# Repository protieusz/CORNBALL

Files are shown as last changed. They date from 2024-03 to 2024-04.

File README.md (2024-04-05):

# CORNBALL
A mod of the Cornelius keyboard with a 25mm integrated trackball and 4 RGBs.  Keyboard is powered by the Waveshare RP2043 Tiny that has a usb c daughterboard PCB.  The switch plate in integrated and is 5mm thick with integrated 25mm trackball holder.  The case is heavily modified from Cool536lc https://github.com/telzo2000/cool536lc to accomodate the trackball in the center.  This pcb also has the option of EVQ roller encoder or a MX switch at the top center.  The modified case files have been removed and close sourced since this is not my original design, telzo2000. You will have to design a case around my pcb.  QMK code is borrowed from aki27 with modification of adding the Cornball matrix into the layout and the rest of the core code is original.

Initial prototype PCBs have a weird flaw. The "Q" switch footprint somehow shifted upwards making it not fit in the switch plate. So I had to bend the 2 pins and cut off the bottom steam holder area in order to fit the switch plate. Then flux solder the pins. The PCB gerber files have since be corrected but untested since I don't want to waste money on another set of 5. Please print at your own risk.

Production Pics






Q Switch Hack















Fusion360 & EasyEDA Renders

Screenshot 2024-03-16 at 7 04 35 PM
Screenshot 2024-03-16 at 2 38 04 AM
Screenshot 2024-03-16 at 2 35 12 AM
Screenshot 2024-03-16 at 2 34 58 AM
Screenshot 2024-03-16 at 2 34 07 AM
Screenshot 2024-03-16 at 2 33 52 AM
Screenshot 2024-03-15 at 12 24 08 PM
Screenshot 2024-03-15 at 12 23 57 PM

Screenshot 2024-03-18 at 1 28 50 AM
Screenshot 2024-03-18 at 1 28 08 AM

Fit Test

















# License

MIT licensed.

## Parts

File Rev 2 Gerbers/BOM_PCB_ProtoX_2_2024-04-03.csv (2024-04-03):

ID | Name | Designator | Footprint | Quantity | Manufacturer Part | Manufacturer | Supplier | Supplier Part | Price | link
1 | RP2040-TINY WITH 3D MODEL | U1 | RP2040-TINY | 1 | 24664 | Waveshare |  |  |  | https://www.waveshare.com/rp2040-tiny.htm?sku=24664
2 | 4.7uF | C17,C19,C20 | C0402 | 3 | CL05A475MP5NRNC | SAMSUNG(三星) | LCSC | C23733 | 0.005 | https://lcsc.com/eda_search?q=C23733&%26type=1&ref=editor
3 | 100nF | C18 | C0402 | 1 | CL05B104KB54PNC | SAMSUNG(三星) | LCSC | C307331 | 0.005 | https://lcsc.com/eda_search?q=C307331&%26type=1&ref=editor
4 | 10kΩ | R10,R12,R13 | R0402 | 3 | 0402WGF1002TCE | UNI-ROYAL(厚声) | LCSC | C25744 | 0.001 | https://lcsc.com/eda_search?q=C25744&%26type=1&ref=editor
5 | 39Ω | R11 | R0402 | 1 | 0402WGJ0390TCE | UNI-ROYAL(厚声) | LCSC | C25164 |  | https://lcsc.com/eda_search?q=C25164&%26type=1&ref=editor
6 | 15kΩ | R14 | R0402 | 1 | 0402WGF1502TCE | UNI-ROYAL(厚声) | LCSC | C25756 | 0.001 | https://lcsc.com/eda_search?q=C25756&%26type=1&ref=editor
7 | SN74LVC1T45QDCKRQ1 | U6 | SC-70-6_L2.0-W1.3-P0.65-LS2.1-BR | 1 | SN74LVC1T45QDCKRQ1 | TI(德州仪器) | LCSC | C139353 | 0.544 | https://lcsc.com/eda_search?q=C139353&%26type=1&ref=editor
8 | AP2127K-ADJTRG1 | U8 | SOT-23-5_L3.0-W1.7-P0.95-LS2.8-BR | 1 | AP2127K-ADJTRG1 | DIODES(美台) | LCSC | C96343 | 0.055 | https://lcsc.com/eda_search?q=C96343&%26type=1&ref=editor
9 | SK6812MINI-E_C5149201 | U13,U14,U15,U16 | LED-SMD_L3.2-W2.8-TR | 4 | SK6812MINI-E | 欧思科光电 | LCSC | C5149201 | 0.162 | https://lcsc.com/eda_search?q=C5149201&%26type=1&ref=editor
10 | PMW3360DM-T2QU | U7 | PMW3360DM-T2QU.PACK | 1 | PMW3360DM-T2QU |  |  |  |  | http://www.pixart.com/upload/PMS0058-PMW3360DM-T2QU-NNDS-R1.30-06042016_20160902201411.pdf
11 | NO | ENCA,ENCB | PIN 1-PIN | 2
12 | SM4007PL | D105,D000,D001,D002,D003,D004,D006,D007,D008,D009,D010,D106,D107,D108,D109,D110,D206,D207,D208,D209,D210,D100,D101,D102,D103,D104,D200,D201,D202,D203,D204,D302,D303,D304,D307,D308,D309 | SOD-123F_L2.8-W1.8-LS3.7-RD | 37 | SM4007PL | MDD | LCSC | C64898 | 0.006 | https://item.szlcsc.com/60254.html
13 | Switch | K105,K307,K000,K001,K002,K003,K004,K006,K007,K008,K009,K010,K106,K107,K108,K109,K110,K206,K207,K208,K209,K210,K100,K101,K102,K103,K104,K200,K201,K202,K203,K204,K302,K303,K304,K308,K309 | CHERRY_MX_100_MILLMAX | 37
14 | Roll Encoder - EVQWGD001 | U105 | EVQWGD001 ENCODER | 1 | EVQWGD001 | Panasonic | Aliexpress | EVQWGD001

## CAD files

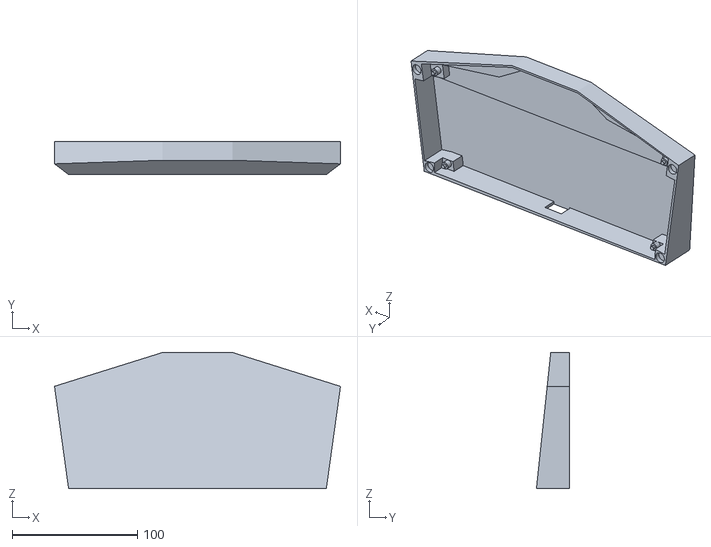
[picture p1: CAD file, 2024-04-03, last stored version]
STLs/cool536lc_bottom higher3mm.stl
228.6 x 26.5 x 108.8

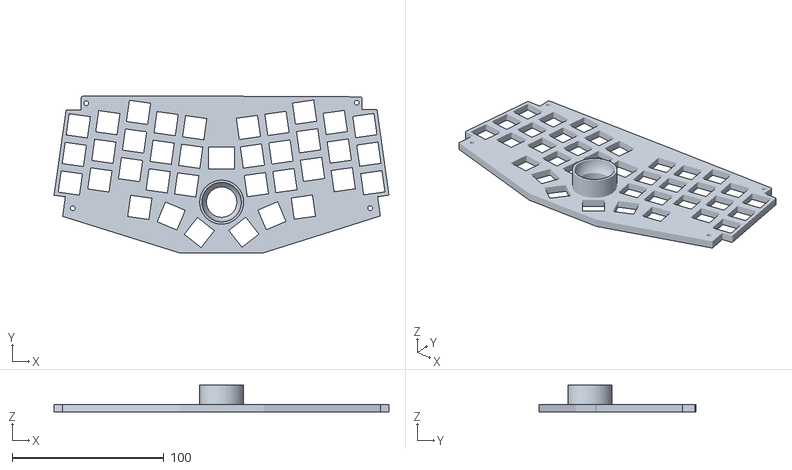
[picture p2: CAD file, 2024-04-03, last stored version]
STLs/ProtoX SwitchPlateFixedSquares.stl
221.0 x 103.3 x 17.8

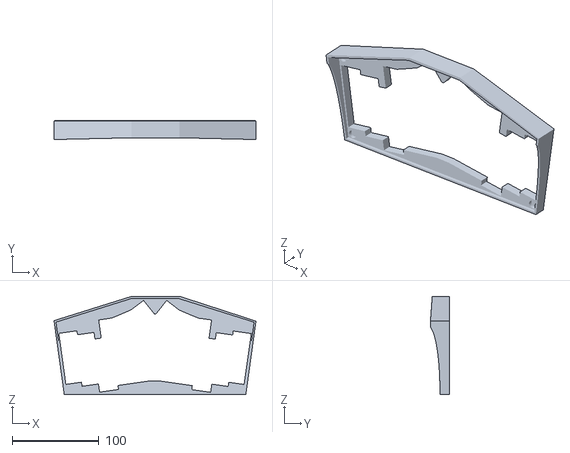
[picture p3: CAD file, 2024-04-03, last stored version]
STLs/cool536lc_top mod.stl
233.1 x 22.0 x 113.5

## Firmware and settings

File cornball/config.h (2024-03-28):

// Copyright 2023 aki27 (@aki27kbd)
// SPDX-License-Identifier: GPL-2.0-or-later

#pragma once

//#define VIAL_KEYBOARD_UID {0xC4, 0x18, 0xCC, 0x6D, 0x1C, 0x16, 0x5B, 0x8D}
//#define VIAL_UNLOCK_COMBO_ROWS {0, 0}
//#define VIAL_UNLOCK_COMBO_COLS {1, 11}

/* VIA */
//#define DYNAMIC_KEYMAP_LAYER_COUNT 8


/* key matrix size */
//#define MATRIX_COLS 13
//#define MATRIX_ROWS 4


/* tapping term */
// #define TAPPING_FORCE_HOLD
//#define TAPPING_TERM 200
// #define IGNORE_MOD_TAP_INTERRUPT

#define RP2040_BOOTLOADER_DOUBLE_TAP_RESET // Activates the double-tap behavior
#define RP2040_BOOTLOADER_DOUBLE_TAP_RESET_TIMEOUT 200U // Timeout window in ms in which the double tap can occur.

#ifdef COMBO_ENABLE
#    define COMBO_COUNT 2
#    define COMBO_TERM 200
#endif

/* Encoder */
//#define ENCODERS_PAD_A { GP11 }
//#define ENCODERS_PAD_B { GP12 }
//#define ENCODER_RESOLUTION 4

/* Matrix*/
//#define MATRIX_COL_PINS { GP25, GP24, GP23, GP22, GP21, GP26, GP27, GP20, GP19, GP18, GP17, GP16, GP13 }
//#define MATRIX_ROW_PINS { GP28, GP10, GP14, GP15 }

/* COL2ROW, ROW2COL */
//#define DIODE_DIRECTION COL2ROW


/* Set 0 if debouncing isn't needed */
//#define DEBOUNCE 5


/* Mechanical locking support. Use KC_LCAP, KC_LNUM or KC_LSCR instead in keymap (Very Important for Scroll Lock!!!) */
#undef LOCKING_SUPPORT_ENABLE
/* Locking resynchronize hack */
#undef LOCKING_RESYNC_ENABLE


/* RGB LED */
//#define WS2812_PIO_USE_PIO1
#define WS2812_DI_PIN GP0

#ifdef RGBLIGHT_ENABLE
    #define RGBLIGHT_LED_COUNT 4
    #define RGBLIGHT_LIMIT_VAL 80
    #define RGBLIGHT_HUE_STEP 10
    #define RGBLIGHT_SAT_STEP 17
    #define RGBLIGHT_VAL_STEP 17

    #define RGBLIGHT_EFFECT_BREATHING
    #define RGBLIGHT_EFFECT_RAINBOW_MOOD
    #define RGBLIGHT_EFFECT_RAINBOW_SWIRL
    #define RGBLIGHT_EFFECT_SNAKE
    #define RGBLIGHT_EFFECT_KNIGHT
    #define RGBLIGHT_EFFECT_CHRISTMAS
    #define RGBLIGHT_EFFECT_STATIC_GRADIENT
    #define RGBLIGHT_EFFECT_TWINKLE
    #define RGBLIGHT_EFFECT_ALTERNATING
#endif


/* Trackball */

#ifdef POINTING_DEVICE_ENABLE

//#    undef RP_SPI_USE_SPI0
//#    define RP_SPI_USE_SPI0 TRUE
//#    undef RP_SPI_USE_SPI1
//#    define RP_SPI_USE_SPI1 FALSE
#    define SPI_DRIVER SPID1

//#    define SPI_SCK_PIN GP22 //6
//#    define SPI_MISO_PIN GP24 //4
//#    define SPI_MOSI_PIN GP23 //7
#    define SPI_SCK_PIN GP14
#    define SPI_MISO_PIN GP12
#    define SPI_MOSI_PIN GP15

#endif


#ifndef PMW33XX_CS_PIN
#    define PMW33XX_CS_PIN GP13
#endif
//#define POINTING_DEVICE_INVERT_X
//#define POINTING_DEVICE_INVERT_Y
//#define ROTATIONAL_TRANSFORM_ANGLE 90
//#define POINTING_DEVICE_ROTATION_90

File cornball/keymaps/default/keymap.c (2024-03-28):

/*
Copyright 2022 aki27

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
You should have received a copy of the GNU General Public License
along with this program.  If not, see <http://www.gnu.org/licenses/>.
*/

#include QMK_KEYBOARD_H

enum combo_events {
  COMBO_DEL,
  COMBO_ESC,
  //COMBO_RCLICK,
  COMBO_LENGTH
};
uint16_t COMBO_LEN = COMBO_LENGTH;

const uint16_t PROGMEM combo_del[] = {KC_Y, KC_H, COMBO_END};
const uint16_t PROGMEM combo_esc[] = {KC_T, KC_G, COMBO_END};
//const uint16_t PROGMEM combo_rclick[] = {KC_MS_BTN1, SCRL_MO, COMBO_END};

combo_t key_combos[] = {
  [COMBO_DEL] = COMBO(combo_del, KC_DEL),
  [COMBO_ESC] = COMBO(combo_esc, KC_ESC),
  //[COMBO_RCLICK] = COMBO(combo_rclick, KC_MS_BTN2),
};

layer_state_t layer_state_set_user(layer_state_t state) {
    return update_tri_layer_state(state, 1, 2, 3);
} 

enum layer_names {
  _BASE,
  _FN1,
  _FN2,
  _FN3
};

const uint16_t PROGMEM keymaps[][MATRIX_ROWS][MATRIX_COLS] = {
    
    [_BASE] = LAYOUT(
        KC_Q,         KC_W, KC_E,    KC_R,    KC_T,                            KC_Y,          KC_U,          KC_I,     KC_O,   KC_P,
        KC_A,         KC_S, KC_D,    KC_F,    KC_G,             SCRL_MO,       KC_H,          KC_J,          KC_K,     KC_L,   KC_SCLN,
        LSFT_T(KC_Z), KC_X, KC_C,    KC_V,    KC_B,                            KC_N,          KC_M,          KC_COMMA, KC_DOT, RSFT_T(KC_SLSH),
                            KC_LGUI, KC_LCTL, LT(1,KC_BSPC),                   LT(2,KC_SPC),  (KC_ENT),      KC_LALT
    ),
    [_FN1] = LAYOUT(
        KC_1,    KC_2,    KC_3,    KC_4,    KC_5,                               KC_6,       KC_7,       KC_8,    KC_9,    KC_0,
        KC_TAB,  _______, _______, _______, _______,             _______,       KC_MINS,    KC_EQL,     KC_LBRC, KC_RBRC, KC_QUOT,
        _______, _______, KC_MUTE, KC_VOLD, KC_VOLU,                            KC_TILD,    KC_GRV,     _______, _______, KC_BSLS,
                          _______, _______, _______,                            KC_MS_BTN1, KC_MS_BTN2, _______
    ),
    [_FN2] = LAYOUT(
        KC_EXLM, KC_AT,   KC_HASH, KC_DLR,  KC_PERC,                            KC_CIRC, KC_AMPR, KC_ASTR, KC_LPRN, KC_RPRN,
        RGB_VAI,  RGB_SAI,  RGB_HUI,  RGB_SPI, RGB_MOD,          _______,       RGB_TOG,  _______,  _______,   _______, _______,
        RGB_VAD,  RGB_SAD,  RGB_HUD,  RGB_SPD, RGB_RMOD,                        _______,  _______, _______, _______, _______,
                          _______, _______, _______,                            _______,  _______, _______
    ),
    [_FN3] = LAYOUT(
        _______, KC_UP, _______, _______, _______,                              KC_F1,   KC_F2,   KC_F3,   KC_F4,   KC_PSCR,
        KC_LEFT, KC_DOWN, KC_RIGHT, _______, _______,            _______,       KC_F5,   KC_F6,   KC_F7,   KC_F8,   KC_F9,
        _______, _______, ROT_L15, ROT_R15, CPI_SW,                             KC_F10,  KC_F11,  KC_F12,  _______, _______,
                          _______, _______, _______,                            _______, _______, _______
    )
};

//bool encoder_update_user(uint8_t index, bool clockwise) {
    //if (index == 0) {
        //if (clockwise) {
            //tap_code(KC_VOLD);
            //tap_code(KC_MS_WH_UP);
        //} else {
            //tap_code(KC_VOLU);
            //tap_code(KC_MS_WH_DOWN);
        //}
    //}
    //return true;
//}

//#if defined(ENCODER_MAP_ENABLE)
//const uint16_t PROGMEM encoder_map[][NUM_ENCODERS][2] = {
    //[0] =  { ENCODER_CCW_CW(KC_MS_WH_UP, KC_MS_WH_DOWN)  },
    //[1] =  { ENCODER_CCW_CW(KC_MS_WH_LEFT, KC_MS_WH_RIGHT)  },
    //[2] =  { ENCODER_CCW_CW(KC_PGUP, KC_PGDN)  },
    //[3] =  { ENCODER_CCW_CW(KC_VOLD, KC_VOLU)  } 
    //[4] =  { ENCODER_CCW_CW(XXXXXXX, XXXXXXX) }
//};
//#endif

//keyevent_t encoder1_ccw = {
    //.key = (keypos_t){.row = 3, .col = 0},
    //.pressed = false
//};

//keyevent_t encoder1_cw = {
    //.key = (keypos_t){.row = 3, .col = 9},
    //.pressed = false
//};

//bool encoder_update_user(uint8_t index, bool clockwise) {
    //if (index == 0) { /* First encoder */
        //if (clockwise) {
            //encoder1_cw.pressed = true;
            //encoder1_cw.time = (timer_read() | 1);
            //action_exec(encoder1_cw);
        //} else {
            //encoder1_ccw.pressed = true;
            //encoder1_ccw.time = (timer_read() | 1);
            //action_exec(encoder1_ccw);
        //}
    //}

    //return true;
//}

//void matrix_scan_user(void) {

    //if (IS_PRESSED(encoder1_ccw)) {
        //encoder1_ccw.pressed = false;
        //encoder1_ccw.time = (timer_read() | 1);
        //action_exec(encoder1_ccw);
    //}

    //if (IS_PRESSED(encoder1_cw)) {
        //encoder1_cw.pressed = false;
        //encoder1_cw.time = (timer_read() | 1);
        //action_exec(encoder1_cw);
    //}

//}

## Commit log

2024-04-03 Case files
    [ProtoX SwitchPlateFixedSquares.stl, cool536lc_bottom higher3mm.stl, cool536lc_top mod.stl]
2024-04-03 Production Gerbers
    [BOM_PCB_ProtoX_2_2024-04-03.csv, PickAndPlace_PCB_ProtoX_2_2024-04-03.csv]

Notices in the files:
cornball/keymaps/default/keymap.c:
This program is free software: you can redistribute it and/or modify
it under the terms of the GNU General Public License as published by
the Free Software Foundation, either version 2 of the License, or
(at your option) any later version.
